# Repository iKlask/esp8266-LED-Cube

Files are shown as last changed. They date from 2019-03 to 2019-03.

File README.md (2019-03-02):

# esp8266-LED-Cube
This is a Blynk based Arduino LED Cube. The cube is a 3x3x3 matrix of LEDs which are controlled via the internet over the Blynk API with an app or with their RESTful api.

<p align="center">
 
</p>

### Arduino Library Requirements:
* [Arduino IDE esp8266 Library](https://arduino-esp8266.readthedocs.io/en/latest/installing.html#boards-manager)
* [Blynk Library](https://www.blynk.cc/getting-started/)
* [WifiManager Library](https://github.com/tzapu/WiFiManager)
* [SimpleTimer Library](https://github.com/schinken/SimpleTimer)

Here is a bill of material with the part numbers I used:

* (x1) ESP-01 esp8266 module
   - Any generic ESP-01 should work
* (x2) 74hc595 Shift Register ICs
   - SN74hc595N
* (x27) 3mm LED (I used Red 1.85v LEDs)
   - WP710A10SRD/E
* (x3) 2n3904 NPN Transistors
   - 2N3904TA
* (x3) 1k Ohms Resistors
   - CF14JT1K00
* (x2) 330 Ohms Resistors
   - CF14JT330R
* (x3) 220 Ohms Resistors
   - CF14JT220R
* (x1) TO-220 3.3v Linear Voltage Regulator
   - LD1117V33C
* (x2) Radial 10uF 50VDC 2mm Electrolytic Capacitors
   - SKR100M1HD11M
* (x1) DC Barrel jack
   - PJ-102AH
* (x1) Barrel Jack Power supply (Must fit the LD1117v33C input requirements)
   - SunFounder DC 9V/650mA Power Supply Plug Adapter
* Break away headers
    - 2 pins for access to Rx/Tx
    - 3 pins + jumper for restarting in programming mode
        - Alternativley use a mini 3 pin single pole, double throw (SPDT) switch

You can copy my project by scanning this QR into the Blynk app. You'll need to supply your new Authtoken in the sketch's ```char auth[]``` field.
<p align="center">
 
</p>

The current sketch expects the following on a Blynk App:

* A Blynk Text LCD to display what the current animation is
   - Input: V2
* A Blynk Menu for Changing the animation of the cube.
   - Output: V0
   - Animations are set to the following indices
       1. Random
       2. Slither
       3. Center Spin
       4. Rain
       5. Flip
       6. Windmill
* A Blynk Slider to adjust the speed of the animations.
   - Output: V1
   - This number is applied as a delay between each "draw", so higher numbers mean slower animations
   - I have mine set to decimal values between 50-5000

A project post-mortem can be seen [here.](https://iklask.github.io/blog/wifi-enabled-3d-led-cube/)

Schematic of the PCB here:
<p align="center">
 
</p>

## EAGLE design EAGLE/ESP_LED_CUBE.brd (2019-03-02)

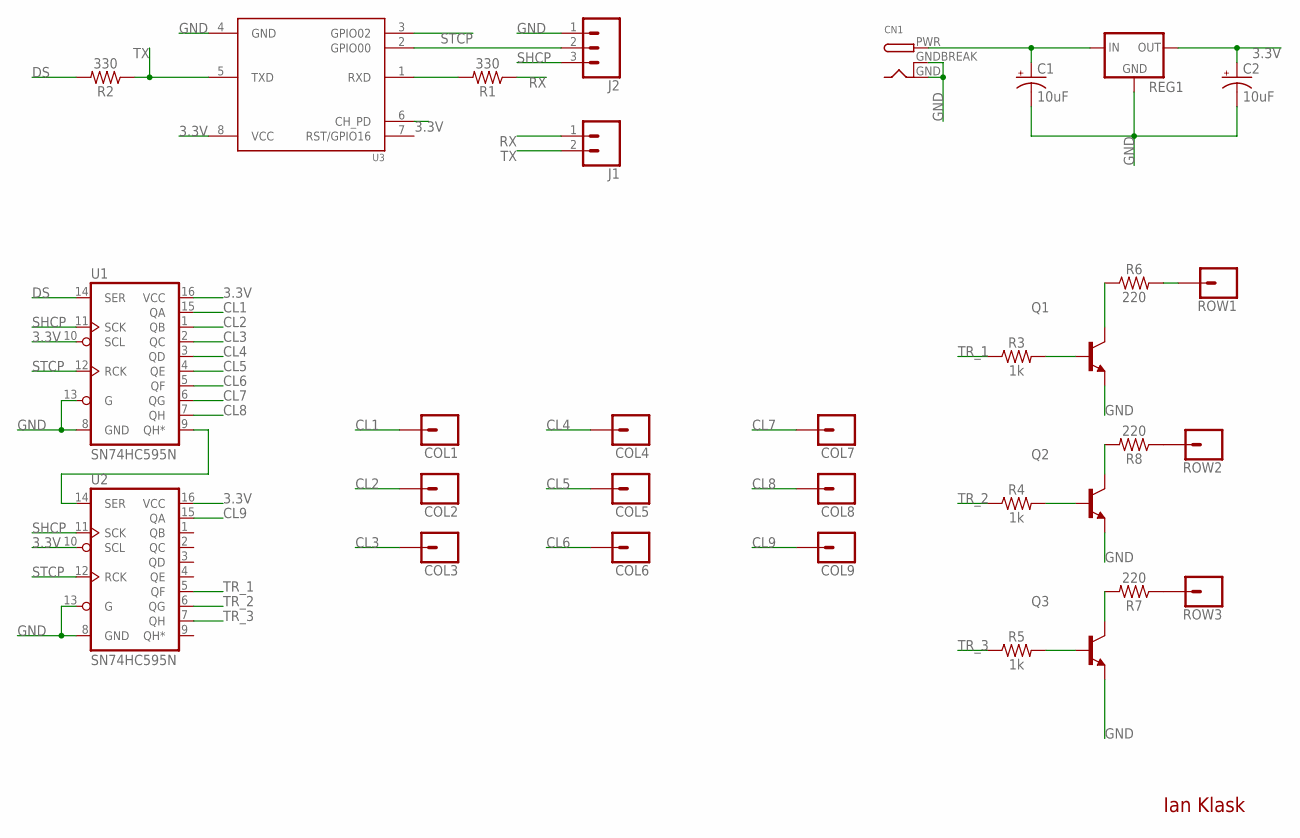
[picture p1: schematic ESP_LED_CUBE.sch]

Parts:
C1, C2: 10uF; CPOL-RADIAL-2.5MM-5MM
CN1: DCBARRELPTH; DCJACK_2MM_PTH
COL1, COL2, COL3, COL4, COL5, COL6, COL7, COL8, COL9: CONN_01; 1X01
J1: CONN_02; 1X02
J2: CONN_03; 1X03
Q1, Q2, Q3: 2N3904; TO92
R1, R2: 330; AXIAL-0.3
R3, R4, R5: 1k; AXIAL-0.3
R6, R7, R8: 220; AXIAL-0.3
REG1: V_REG_LD1117VXX; 78XXL
ROW1, ROW2, ROW3: CONN_01; 1X01
U1, U2: SN74HC595N; DIP16
U3: ESP8266-01/ESP-01; XCVR_ESP8266-01/ESP-01

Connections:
3.3V: C2.1 (+), REG1.GND (OUT), U1.10 (SCL), U1.16 (VCC), U2.10 (SCL), U2.16 (VCC), U3.6 (CH_PD), U3.8 (VCC)
CL1: COL1.1, U1.15 (QA)
CL2: COL2.1, U1.1 (QB)
CL3: COL3.1, U1.2 (QC)
CL4: COL4.1, U1.3 (QD)
CL5: COL5.1, U1.4 (QE)
CL6: COL6.1, U1.5 (QF)
CL7: COL7.1, U1.6 (QG)
CL8: COL8.1, U1.7 (QH)
CL9: COL9.1, U2.15 (QA)
DS: R2.P$2 (2), U1.14 (SER)
GND: C1.2 (-), C2.2 (-), CN1.GND, CN1.GNDBREAK, J2.1, Q1.3 (E), Q2.3 (E), Q3.3 (E), REG1.IN (GND), U1.8 (GND), U1.13 (G), U2.8 (GND), U2.13 (G), U3.4 (GND)
unnamed: C1.1 (+), CN1.PWR, REG1.OUT (IN)
unnamed: U1.9 (QH*), U2.14 (SER)
unnamed: R1.P$2 (2), U3.1 (RXD)
unnamed: Q1.1 (C), R6.P$1 (1)
unnamed: R7.P$1 (1), ROW3.1
unnamed: R8.P$1 (1), ROW2.1
unnamed: R6.P$2 (2), ROW1.1
unnamed: Q3.1 (C), R7.P$2 (2)
unnamed: Q2.1 (C), R8.P$2 (2)
unnamed: Q3.2 (B), R5.P$2 (2)
unnamed: Q2.2 (B), R4.P$2 (2)
unnamed: Q1.2 (B), R3.P$2 (2)
unnamed: J2.2, U3.2 (GPIO00)
RX: J1.1, R1.P$1 (1)
SHCP: J2.3, U1.11 (SCK), U2.11 (SCK)
STCP: U1.12 (RCK), U2.12 (RCK), U3.3 (GPIO02)
TR_1: R3.P$1 (1), U2.5 (QF)
TR_2: R4.P$1 (1), U2.6 (QG)
TR_3: R5.P$1 (1), U2.7 (QH)
TX: J1.2, R2.P$1 (1), U3.5 (TXD)

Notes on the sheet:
Ian Klask

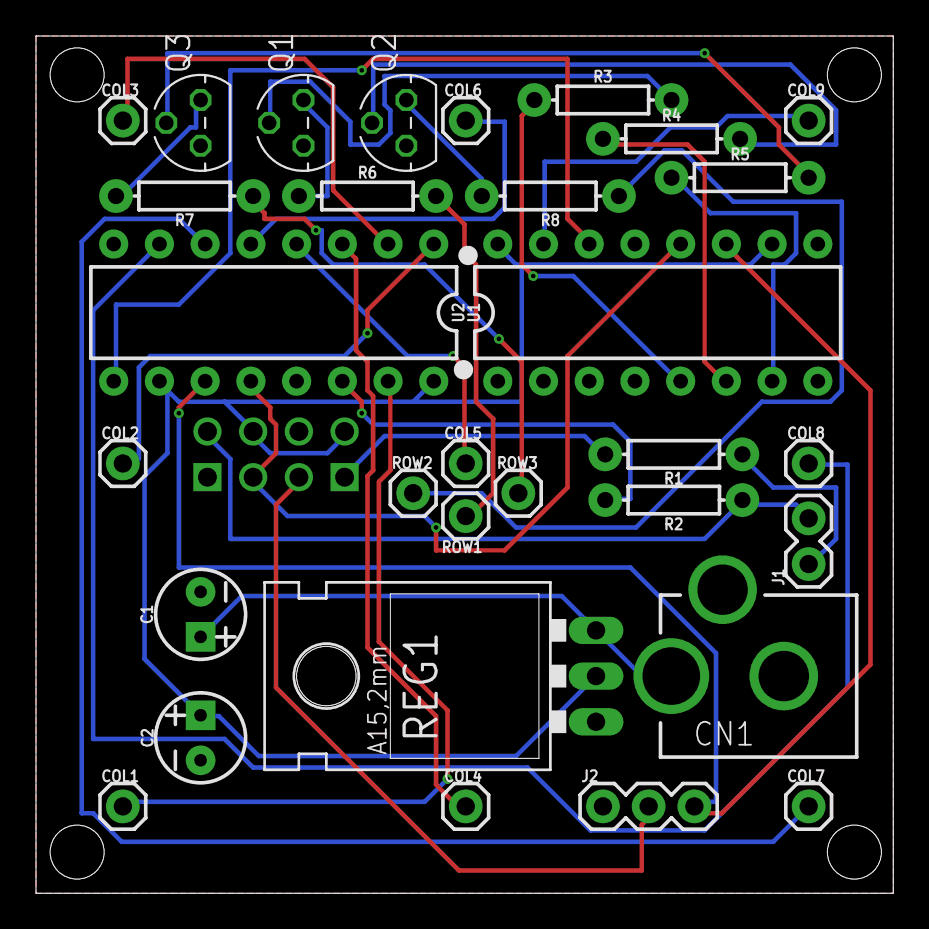
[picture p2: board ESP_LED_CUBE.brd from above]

Board: 2 copper layers, 47.6 x 47.6 mm, 32 parts (1 on the bottom side), 32 nets.

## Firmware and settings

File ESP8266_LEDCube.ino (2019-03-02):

#include <FS.h>                   //this needs to be first, or it all crashes and burns...

#include <DNSServer.h>
#include <ESP8266WebServer.h>
#include <WiFiManager.h>          //https://github.com/tzapu/WiFiManager
#include <ESP8266WiFi.h>

#include <BlynkSimpleEsp8266.h>

#include "CubeFunctions.h"
#include "Animations.h"
#include <SimpleTimer.h>

//  Blynk Auth Token
char auth[] = "YOUR BLINK AUTH TOKEN HERE";

//  Timer and id for Animation function
SimpleTimer timer;
int ani_ID = 0;
int shuffle_ID = 10;
int current_ani = 0;

//  Function Pointer to current Animation
void (*ani_func)();

//  Delay in ms between each animation update
int t_delay = 250;

WidgetLCD lcd(V2);
void LCD_Animation(char* _ani)
{
  lcd.clear();
  lcd.print(0, 0, "Animation:");
  lcd.print(0, 1, _ani);
}

void Shuffle_Animations()
{
  //*
  int _rand = current_ani; 
  while(_rand == current_ani)
  {
    _rand = (int)random(2,7);
  }
  current_ani = _rand;
  //*/
  
  switch(current_ani)
  {
    case 2:
      LCD_Animation("Slither");
      
      ani_func = &ani_Snake;
      //current_ani = 2;
      t_delay = 100;
      Blynk.virtualWrite(V1,100);
      break;
    case 3:
      LCD_Animation("Center Spin");
      
      ani_func = &ani_Spin;
      //current_ani = 3;
      t_delay = 150;
      Blynk.virtualWrite(V1,150);
      break;
    case 4:
      LCD_Animation("Rain");
      
      ani_func = &ani_Rain;
      //current_ani = 4;
      t_delay = 200;
      Blynk.virtualWrite(V1,200);
      break;
    case 5:
      LCD_Animation("Flip");
      
      ani_func = &ani_Flip;
      //current_ani = 5;
      t_delay = 450;
      Blynk.virtualWrite(V1,450);
      break;
    case 6:
      LCD_Animation("Windmill");
      
      ani_func = &ani_Windmill;
      //current_ani = 6;
      t_delay = 200;
      Blynk.virtualWrite(V1,200);
      break;
  }

  timer.deleteTimer(ani_ID);
  ani_ID = timer.setInterval(t_delay, ani_func);
  shuffle_ID = timer.setTimeout(10000, Shuffle_Animations);
}


//* === BLYNK functions ===
///App Connect Sync
BLYNK_APP_CONNECTED()
{
  Blynk.syncAll();
  Blynk.virtualWrite(V1, t_delay);
  lcd.clear();
}

///Menu
BLYNK_WRITE(V0)
{
  switch(param.asInt())
  {
    case 1:
      current_ani = 1;
      Shuffle_Animations();
      break;
    case 2:
      LCD_Animation("Slither");
      
      timer.deleteTimer(shuffle_ID); //just in case still random
      ani_func = &ani_Snake;
      current_ani = 2;
      break;
    case 3:
      LCD_Animation("Center Spin");
      
      timer.deleteTimer(shuffle_ID); //just in case still random
      ani_func = &ani_Spin;
      current_ani = 3;
      break;
    case 4:
      LCD_Animation("Rain");
      
      timer.deleteTimer(shuffle_ID); //just in case still random
      ani_func = &ani_Rain;
      current_ani = 4;
      break;
    case 5:
      LCD_Animation("Flip");
      
      timer.deleteTimer(shuffle_ID); //just in case still random
      ani_func = &ani_Flip;
      current_ani = 5;
      break;
    case 6:
      LCD_Animation("Windmill");
    
      timer.deleteTimer(shuffle_ID); //just in case still random
      ani_func = &ani_Windmill;
      current_ani = 6;
      break;
  }
  
  timer.deleteTimer(ani_ID);
  ani_ID = timer.setInterval(t_delay, ani_func);
}
///Animation Speed
BLYNK_WRITE(V1)
{
  t_delay = param.asInt(); // assigning incoming value from pin V1 to a variable

  //Sets the timer to a new delay
  timer.deleteTimer(ani_ID);
  ani_ID = timer.setInterval(t_delay, ani_func);
}
//* ==========================/

void configModeCallback (WiFiManager *myWiFiManager) {
  Serial.println("Entered config mode");
  Serial.println(WiFi.softAPIP());

  Serial.println(myWiFiManager->getConfigPortalSSID());
}

void WifiSetUp()
{
  //*/====================
  WiFiManager wifiManager;

  //  set callback that gets called when connecting to previous WiFi fails, and enters Access Point mode
  wifiManager.setAPCallback(configModeCallback);

  //  set static ip
  ////wifiManager.setSTAStaticIPConfig(IPAddress(192,168,10,111), IPAddress(192,168,10,90), IPAddress(255,255,255,0));

  //  set minimu quality of signal so it ignores AP's under that quality
  //  defaults to 8%
  ///wifiManager.setMinimumSignalQuality(50);

  wifiManager.setDebugOutput(false);

  //  sets timeout until configuration portal gets turned off
  //  useful to make it all retry or go to sleep, __in seconds__
  wifiManager.setTimeout(120);  //2 min
  wifiManager.setConnectTimeout(120);

  //alternative to force AP mode: wifiManager.startConfigPortal()
  if (!wifiManager.autoConnect("ESPConnect", "ESPpass0")) {
    Serial.println("failed to connect and hit timeout...");
    //reset and try again, or maybe put it to deep sleep
    ESP.reset();
    delay(1000);
  }
  //================*/
}

void setup()
{
  // Debug console
  Serial.begin(115200);
  randomSeed(analogRead(0));

  pinMode(DS_pin, OUTPUT);
  pinMode(STCP_pin, OUTPUT);
  pinMode(SHCP_pin, OUTPUT);
  writeReg();

  
  WifiSetUp();

  Blynk.config(auth);
  Blynk.connect();
  //*/


  Serial.println("SETUP DONE");

  
  //* Set starting Animation
  ani_func = &ani_Snake;
  ani_ID = timer.setInterval(t_delay, ani_func);
  //*/

  // or:
  //Shuffle_Animations();
}

void loop()
{
  Blynk.run();
  timer.run();
  
  Draw();
}

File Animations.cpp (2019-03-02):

#include "Animations.h"
#include "CubeFunctions.h"
#include <Arduino.h> 

int counter_Snake = 0;
int snake_pat_1[9] = {0,1,2,5,4,3,6,7,8};
int snake_pat_2[9] = {8,7,6,3,4,5,2,1,0};

int spin_pat[8] = {0,1,2,5,8,7,6,3};
int counter_Spin = 0;

int counter_windmill = 0;

int counter_Flip = 1;

//Loops through in a snakeing pattern
  //Level 1: 012 543 678
  //Level 2: 876 345 210
  //Level 3: 012 543 678
void ani_Snake()
{
  ClearLevels();
  // Level 1
  if(counter_Snake < 9)
  {
    SetLed( snake_pat_1[counter_Snake], LEVEL_1);
    counter_Snake++;
  }
  //Level 2
  else if(counter_Snake < 18)
  {
    SetLed( snake_pat_2[counter_Snake - 9], LEVEL_2);
    counter_Snake++;
  }
  //Level 3
  else
  {
    SetLed( snake_pat_1[counter_Snake - 18], LEVEL_3);
    if(counter_Snake >= 26){ counter_Snake = 0; }
    else { counter_Snake++; }
  }
}

//Center Col stays on while outer Cols spin around center
//cols: 0,1,2,5,8,7,6,3
void ani_Spin()
{
  ClearLevels();
  SetLed(4,LEVEL_1);
  SetLed(4,LEVEL_2);
  SetLed(4,LEVEL_3);

  SetLed(spin_pat[counter_Spin],LEVEL_1);
  SetLed(spin_pat[counter_Spin],LEVEL_2);
  SetLed(spin_pat[counter_Spin],LEVEL_3);
  counter_Spin++;
  if(counter_Spin >= 8) { counter_Spin = 0; }
}

//Random Rain drops
void ani_Rain()
{
  //Push all the levels down
  DropLevels();

  //Pick some new bits
  int i = (int)random(1,5);
  for(int j = 0; j < i; j++)
  {
    int r = (int)random(9);
    SetLed(r, LEVEL_3);
  }
}


// L1: 345 L3: 345
// L1: 012 L3: 678
// L2: 012345678
// L1: 678 L3: 012
void ani_Windmill()
{
  ClearLevels();
  SetLed(3,LEVEL_2);
  SetLed(4,LEVEL_2);
  SetLed(5,LEVEL_2);

  switch(counter_windmill)
  {
    case 0:
      //Pat_1
      SetLed(3,LEVEL_1);
      SetLed(4,LEVEL_1);
      SetLed(5,LEVEL_1);
      
      SetLed(3,LEVEL_3);
      SetLed(4,LEVEL_3);
      SetLed(5,LEVEL_3);
      
      counter_windmill++;
      break;
    case 1:
      //Pat_2
      SetLed(0,LEVEL_1);
      SetLed(1,LEVEL_1);
      SetLed(2,LEVEL_1);
      
      SetLed(6,LEVEL_3);
      SetLed(7,LEVEL_3);
      SetLed(8,LEVEL_3);
      counter_windmill++;
      break;
    case 2:
      //Pat_3
      SetLed(0,LEVEL_2);
      SetLed(1,LEVEL_2);
      SetLed(2,LEVEL_2);
      SetLed(6,LEVEL_2);
      SetLed(7,LEVEL_2);
      SetLed(8,LEVEL_2);
      counter_windmill++;
      break;
    case 3:
      //Pat_4
      SetLed(6,LEVEL_1);
      SetLed(7,LEVEL_1);
      SetLed(8,LEVEL_1);
      
      SetLed(0,LEVEL_3);
      SetLed(1,LEVEL_3);
      SetLed(2,LEVEL_3);
      counter_windmill = 0;
      break;
    defualt:
      counter_windmill = 0;
      break;
  }
}

//Flipping Cube  
  //1 012
  //2 048
  //3 036
  //4 642
  //5 678
  //6 048
  //7 258
  //8 642
void ani_Flip()
{
  ClearLevels();
  switch(counter_Flip)
  {
    case 1:
      for(int lvl = 13; lvl < 16; lvl++)
      {
        SetLed(0,lvl);
        SetLed(1,lvl);
        SetLed(2,lvl);
      }
      break;
    case 2:
      for(int lvl = 13; lvl < 16; lvl++)
      {
        SetLed(0,lvl);
        SetLed(4,lvl);
        SetLed(8,lvl);
      }
      break;
    case 3:
      for(int lvl = 13; lvl < 16; lvl++)
      {
        SetLed(0,lvl);
        SetLed(3,lvl);
        SetLed(6,lvl);
      }
      break;
    case 4:
      for(int lvl = 13; lvl < 16; lvl++)
      {
        SetLed(6,lvl);
        SetLed(4,lvl);
        SetLed(2,lvl);
      }
      break;
    case 5:
      for(int lvl = 13; lvl < 16; lvl++)
      {
        SetLed(6,lvl);
        SetLed(7,lvl);
        SetLed(8,lvl);
      }
      break;
    case 6:
      for(int lvl = 13; lvl < 16; lvl++)
      {
        SetLed(0,lvl);
        SetLed(4,lvl);
        SetLed(8,lvl);
      }
      break;
    case 7:
      for(int lvl = 13; lvl < 16; lvl++)
      {
        SetLed(2,lvl);
        SetLed(5,lvl);
        SetLed(8,lvl);
      }
      break;
    case 8:
      for(int lvl = 13; lvl < 16; lvl++)
      {
        SetLed(6,lvl);
        SetLed(4,lvl);
        SetLed(2,lvl);
      }
      counter_Flip = 0; //will set to 1 on the ++
      break;
  }
  counter_Flip++;
}

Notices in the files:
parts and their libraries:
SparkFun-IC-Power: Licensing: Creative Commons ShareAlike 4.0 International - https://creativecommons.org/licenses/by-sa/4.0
